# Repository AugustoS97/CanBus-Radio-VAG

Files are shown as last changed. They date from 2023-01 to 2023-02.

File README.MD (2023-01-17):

# CAN BUS interface for powering up the DSP/Sound System Amplifier for SKODA, VOLKSWAGEN, AUDI AND SEAT vehicules with non original radios

System for switching on original speakers amplifier and DSP with CAN BUS control.

Tested in a Skoda Octavia 1Z (year 2005) Edition 100 with Audience radio (6-CD changer included) and 12-speaker Sound system with active DSP controlled by CAN BUS (model 1Z0 035 456).

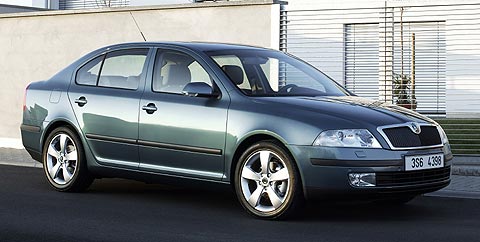
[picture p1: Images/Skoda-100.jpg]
Octavia Skoda Octavia Edition 100 (Model tested)


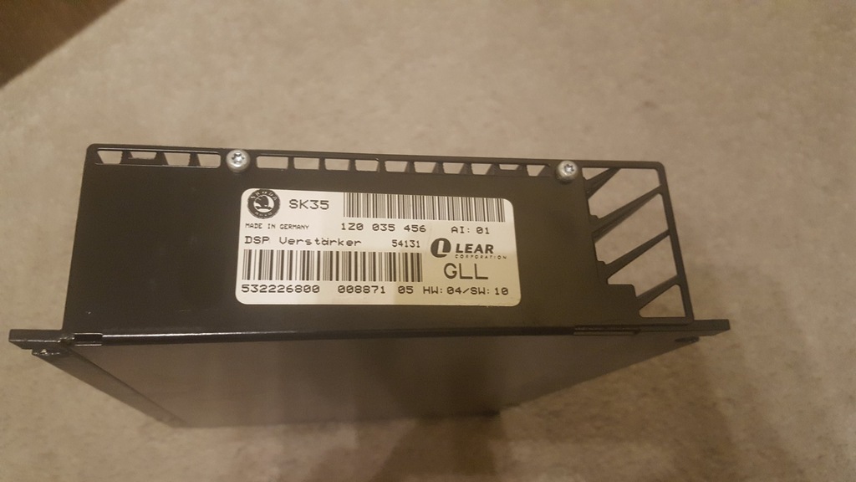
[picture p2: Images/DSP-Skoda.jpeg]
DSP Skoda DSP Picture


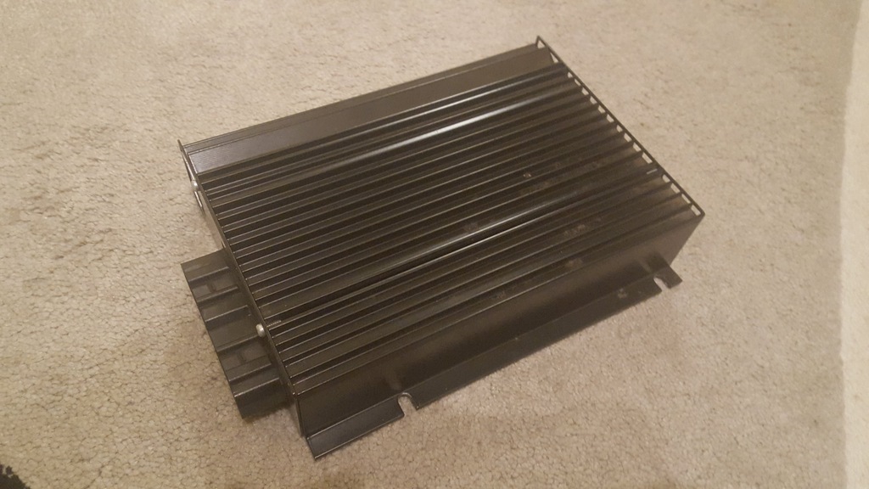
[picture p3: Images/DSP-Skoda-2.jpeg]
DSP Skoda TOP DSP TOP Picture


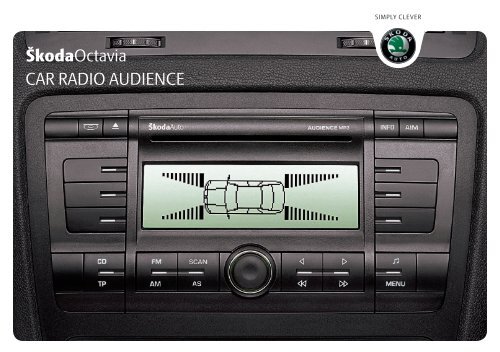
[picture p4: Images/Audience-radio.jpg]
Original radio Audience Original Car Radio


## Solution provided

A CAN controller has been developed using an ATMega 328P microcontroller (Arduino) and the CAN BUS MCP2515 interface with a TJA1050T transceiver. It allows direct power supply to the vehicle voltage (up to 20V) thanks to the MP2307 DC/DC regulator.

This interface enables the following functions:
- Switching on the sound/amplifier controller, active equaliser or DSP of a VAG group vehicle.
- Getting a 12V signal when the vehicle's ignition is switched on (work in progress).
- Getting a 12V signal when the reverse gear is engaged (work in progress).
- Control a fan to cool the vehicle radio when the vehicle radio is on.
- Getting a signal from the steering wheel controls to integrate them into a conventional radio (work in progress).

### Prototipe

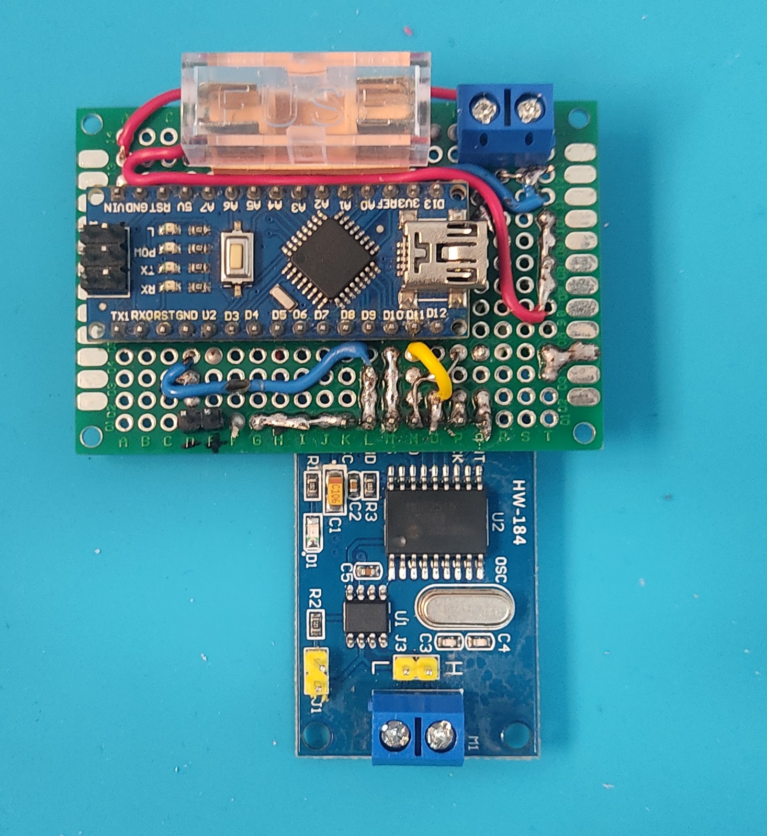
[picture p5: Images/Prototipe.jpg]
Prototipe


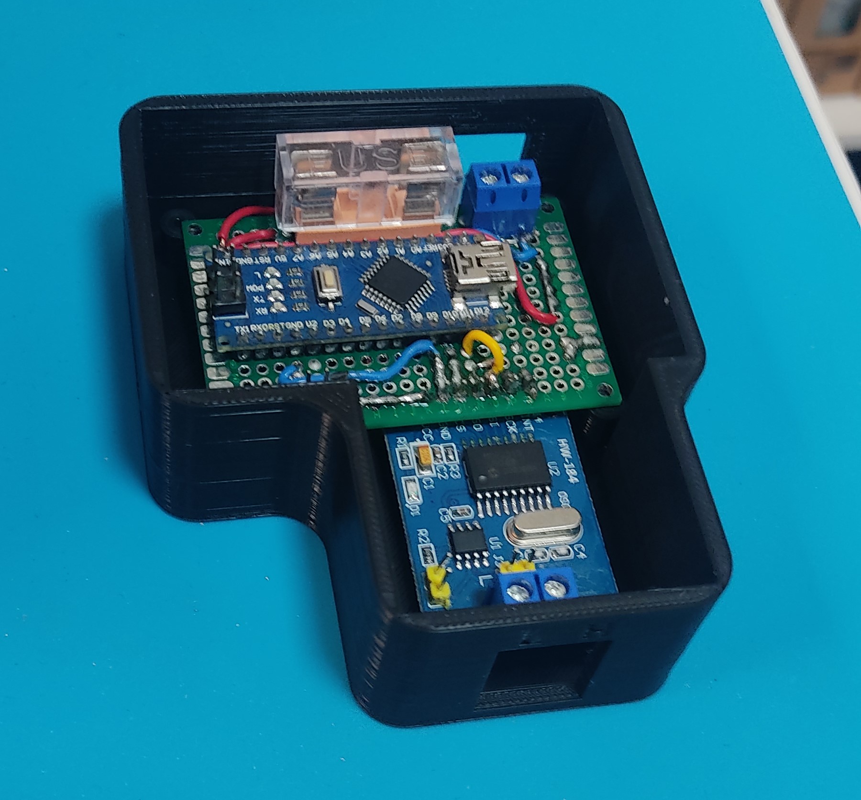
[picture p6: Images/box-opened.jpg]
Box top


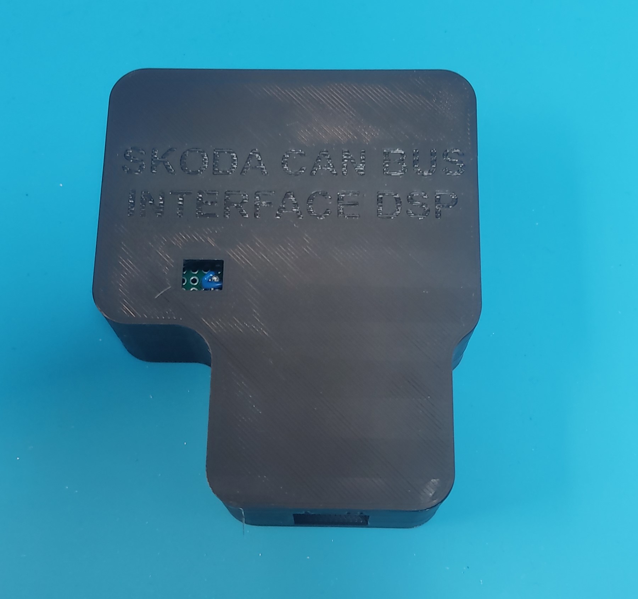
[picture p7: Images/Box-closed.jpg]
Box closed


### Final solution

The PCB designed has a JST XH 2.54 connector with 8 pins to connect to the radio and car wires. Also the interface has a ICSP and Serial connection to program and debug.

#### Electronic eschema

The connection eschema and PCB design is the following:

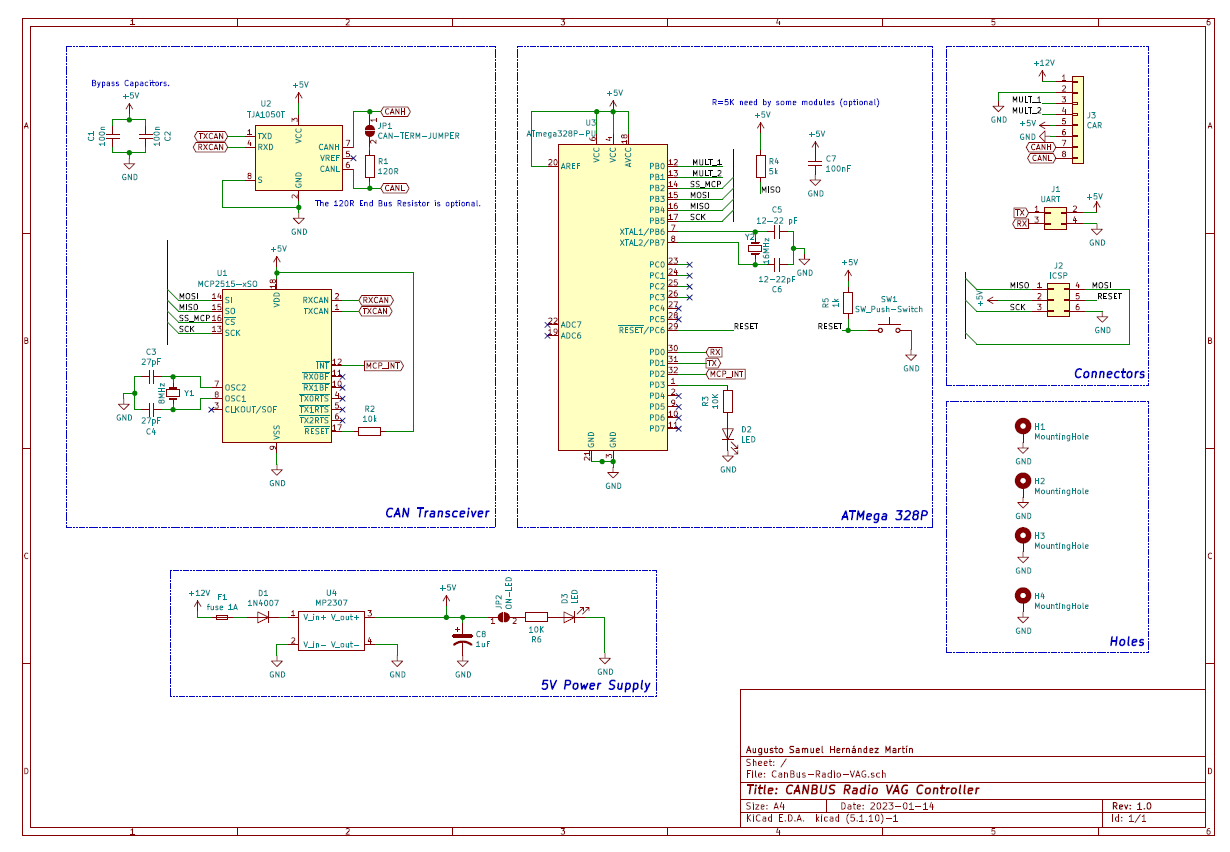
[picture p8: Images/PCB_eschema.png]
Eschema


#### PCB Designed

The 3D model of the PCB is as follow:

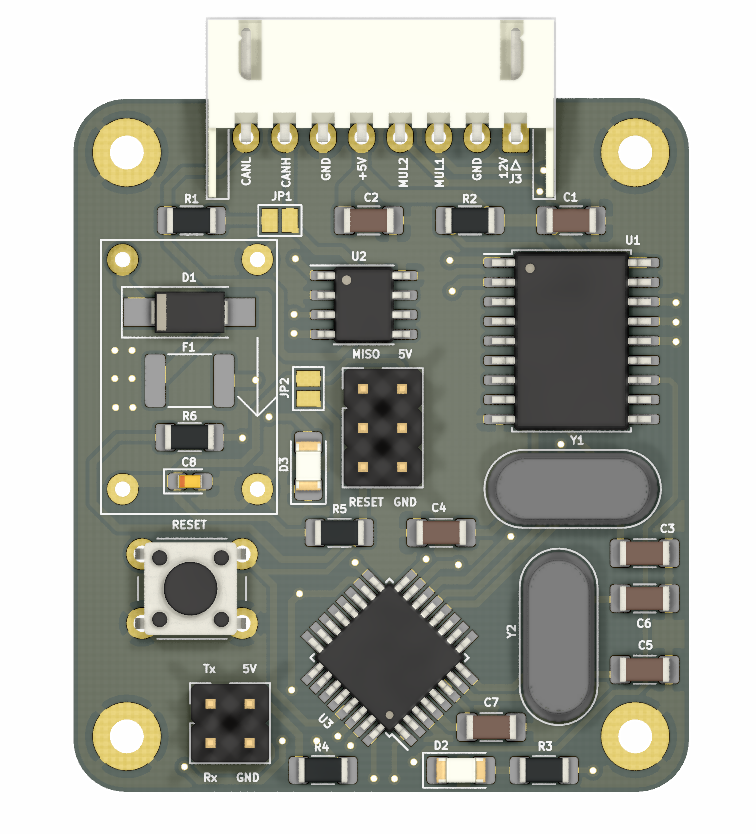
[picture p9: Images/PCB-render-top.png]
PCB TOP


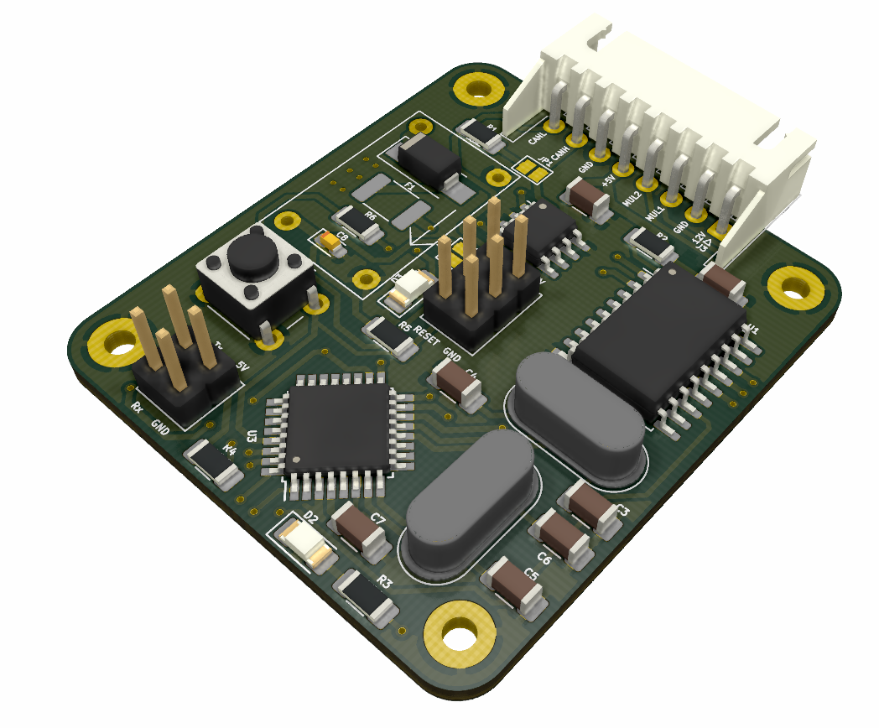
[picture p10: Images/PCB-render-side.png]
PCB SIDE


### Working in vehicule

It has been tested in my Skoda Octavia with an Android chineese radio, and using the module developed it is possible to use the original amplifier with the original soundsystem. Without this CAN Controller it is not possible to power on the DSP, so is impossible to get sound by the speakers. 

Here is possible to see some pictures of the process:

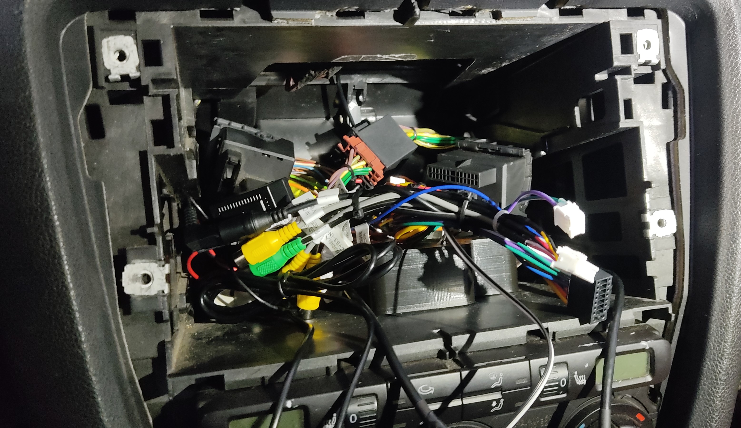
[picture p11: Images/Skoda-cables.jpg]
Making some wires


- Work in progress.

## In-vehicle wiring diagram with any radio

The connection to the module must be made as follows:

- 12V in, must be connected to an ignition after contact or to the AMP REMOTE pin of the radio, so that the module is only activated when the radio is switched on.
- GND, must be connected to the vehicle chassis or to a GND of the radio.
- CAN H, must be connected to the CAN HIGH pin of the vehicle (on the FAKRA connector)
- CAN L, must be connected to the vehicle's CAN LOW pin (on the FAKRA connector)
- Mult1 and Mult 2, are reverse and ignition signals (development in progress).

## Software requirements

To load the code on the developed board, an ISP programmer and the Arduino IDE must be used.
- The libraries required for the project are as follows:
  - [CAN Shield library](https://github.com/coryjfowler/MCP_CAN_lib)

## BOM for PCB

It is possible to find the BOM with the LCSC reference [here](/Electronic/PCB/CanBus-Radio-VAG-V1.0/ASSEMBLY/CanBus-Radio-VAG-V1.0-BOM.xlsx).

Also, the GERBER file for one PCB and for a panel (panelizing the order, you can reduce the cost) is available [here](/Electronic/PCB/CanBus-Radio-VAG-V1.0/GERBER/CanBus-Radio-VAG-V1-Gerber.zip).

## Extra functions

To activate the front sensors from the vehicle's parking button, the power pin of the parking button connector must be connected to the reverse signal from the camera. It is recommended that a 1N4007 diode is used to prevent current flowing back to the button from the radio or from the button to the CAN BUS module.

Here you can see an scheme of this connection.

## Buy the CAN Controller

If you want to buy a CAN Controller to enable your DSP and use the original sound system with non-stock radios in Volkswagen, Audi, Skoda and Seat, you can contact with me by email (augustosamuelhdezmartin@gmail.com) or you can buy it in E-bay here.

## Other tools

Also there is a [folder](/Arduino/tools/CanHacker/) with the CAN HACKER software and the code to upload to Arduino to use a MCP2515 module + Arduino Nano as a CAN BUS sniffer and get all the message in the PC using the CAN HACKER software. With this method I could find the radio messages, so I could create this CAN BUS interface.

## Links of interest

Some interesting links:

- [A way to use stock amp with after market radio SKODA](https://www.briskoda.net/forums/topic/449813-solved-better-way-of-using-stock-amp-with-after-market-radio/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)
- [How to use after market radio with the stock amplifier in SKODA, SEAT, VOLKSWAGEN and AUDI cars](https://www.briskoda.net/forums/topic/378504-solved-how-to-use-stock-amplifier-with-after-market-hu/)

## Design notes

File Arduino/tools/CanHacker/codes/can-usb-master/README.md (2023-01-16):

# CanHacker (lawicel) CAN adapter on Arduino + MCP2515

Testes with Arduino Nano.
On Arduino Uno have problem with too long boot period and losing first command when work with CanHacker application

## Installation

1. Install [MCP2515 Library](https://github.com/autowp/arduino-mcp2515)
2. Install [CanHacker Library](https://github.com/autowp/arduino-canhacker)
3. Configure sketch: MCP2515 CS pin, SoftwareSerial pins if required, change baudrates
4. Use with [CanHacker](http://www.mictronics.de/projects/usb-can-bus/) or CANreader (soon)

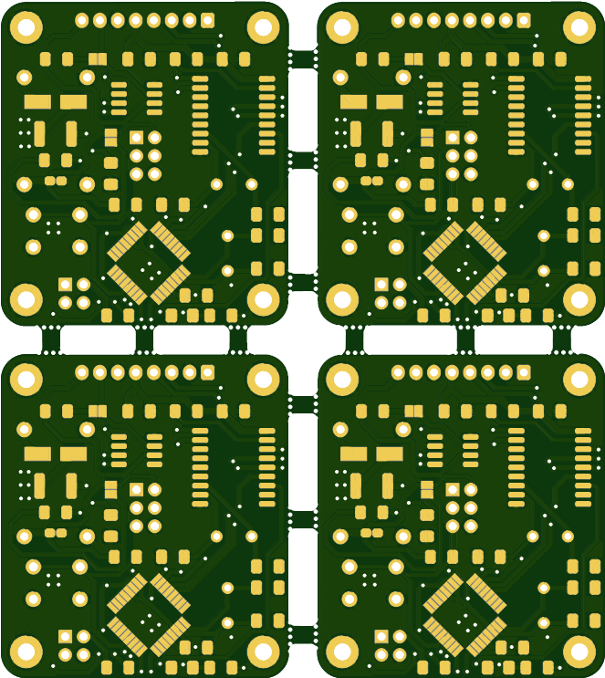
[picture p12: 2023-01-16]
Electronic/PCB/CanBus-Radio-VAG-V1.0/GERBER/Panelize/Untitled_Combined_Top.png

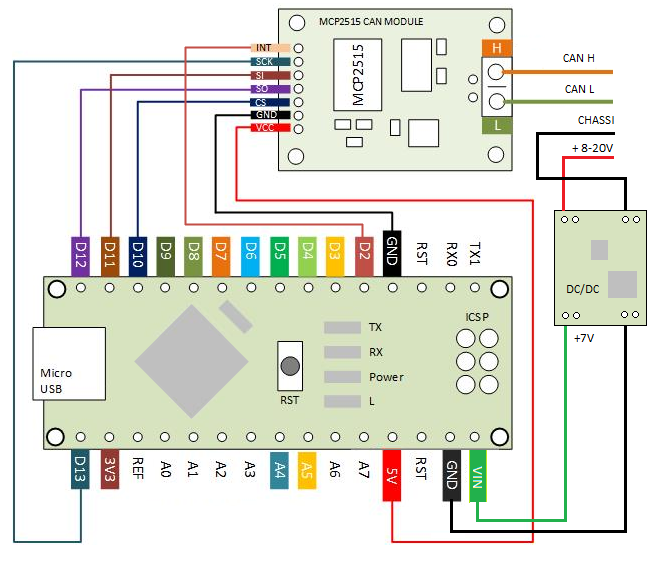
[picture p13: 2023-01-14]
Electronic/Eschemes/Esquema.png

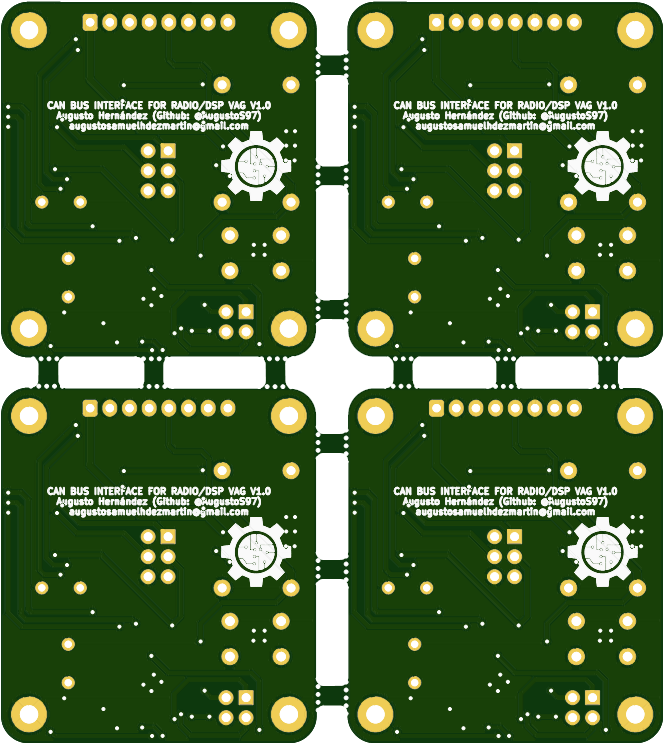
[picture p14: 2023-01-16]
Electronic/PCB/CanBus-Radio-VAG-V1.0/GERBER/Panelize/Untitled_Combined_Bottom.png

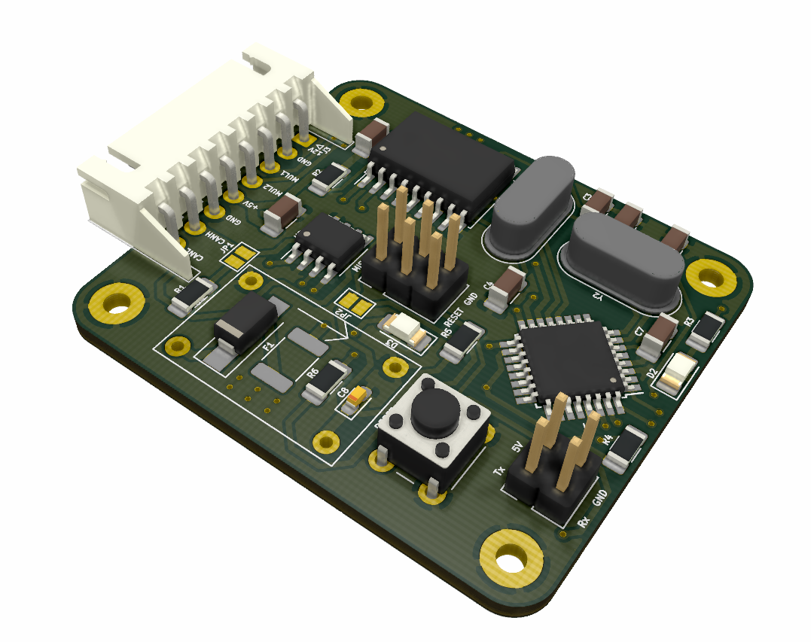
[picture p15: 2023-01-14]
Images/PCB-render-other-side.png

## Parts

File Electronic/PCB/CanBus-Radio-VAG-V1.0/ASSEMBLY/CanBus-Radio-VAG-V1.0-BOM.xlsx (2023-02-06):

 | Columna2 | Columna3 | Columna1 | Columna4
Comment | Designator | Footprint | LCSC Part Number | Qnty
100n | C1, C2, C7 | Capacitor_SMD:C_1206_3216Metric_Pad1.33x1.80mm_HandSolder | C840121 | 3
27pF | C3, C4, | Capacitor_SMD:C_1206_3216Metric_Pad1.33x1.80mm_HandSolder | C1899 | 2
22pF | C5, C6 | Capacitor_SMD:C_1206_3216Metric_Pad1.33x1.80mm_HandSolder | C565687 | 2
1uF | C8, | Capacitor_Tantalum_SMD:CP_EIA-1608-10_AVX-L_Pad1.25x1.05mm_HandSolder | C307912 | 1
1N4007 | D1, | Diode_SMD:D_SMA_Handsoldering | C2909831 | 1
LED | D2, D3, | LED_SMD:LED_1206_3216Metric_Pad1.42x1.75mm_HandSolder | C375458 | 2
fuse 1A | F1, | Fuse:Fuse_1812_4532Metric_Pad1.30x3.40mm_HandSolder | C151169 | 1
UART | J1, | Connector_PinHeader_2.54mm:PinHeader_2x02_P2.54mm_Vertical | C706892 | 1
ICSP | J2, | Connector_PinHeader_2.54mm:PinHeader_2x03_P2.54mm_Vertical | C706893 | 1
CAR | J3, | Connector_JST:JST_XH_S8B-XH-A-1_1x08_P2.50mm_Horizontal |  | 1
120R | R1, | Resistor_SMD:R_1206_3216Metric_Pad1.30x1.75mm_HandSolder | C114928 | 1
10k | R2, | Resistor_SMD:R_1206_3216Metric_Pad1.30x1.75mm_HandSolder | C3018037 | 1
10K | R3, R6, | Resistor_SMD:R_1206_3216Metric_Pad1.30x1.75mm_HandSolder | C3018037 | 2
5k | R4, | Resistor_SMD:R_1206_3216Metric_Pad1.30x1.75mm_HandSolder | C136458 | 1
1k | R5, | Resistor_SMD:R_1206_3216Metric_Pad1.30x1.75mm_HandSolder | C408770 | 1
SW_Push-Switch | SW1, | Button_Switch_THT:SW_PUSH_6mm_H5mm | C2828578 | 1
MCP2515-xSO | U1, | Package_SO:SOIC-18W_7.5x11.6mm_P1.27mm | C12368 | 1
TJA1050T | U2, | Package_SO:SOIC-8_3.9x4.9mm_P1.27mm | C6952 | 1
ATmega328P-PU | U3, | SmartBMS:TQFP-32_7x7mm_P0.8mm | C14877 | 1
8MHz | Y1, | Crystal:Crystal_HC49-4H_Vertical | C655216 | 1
16MHz | Y2, | Crystal:Crystal_HC49-4H_Vertical | C390745 | 1

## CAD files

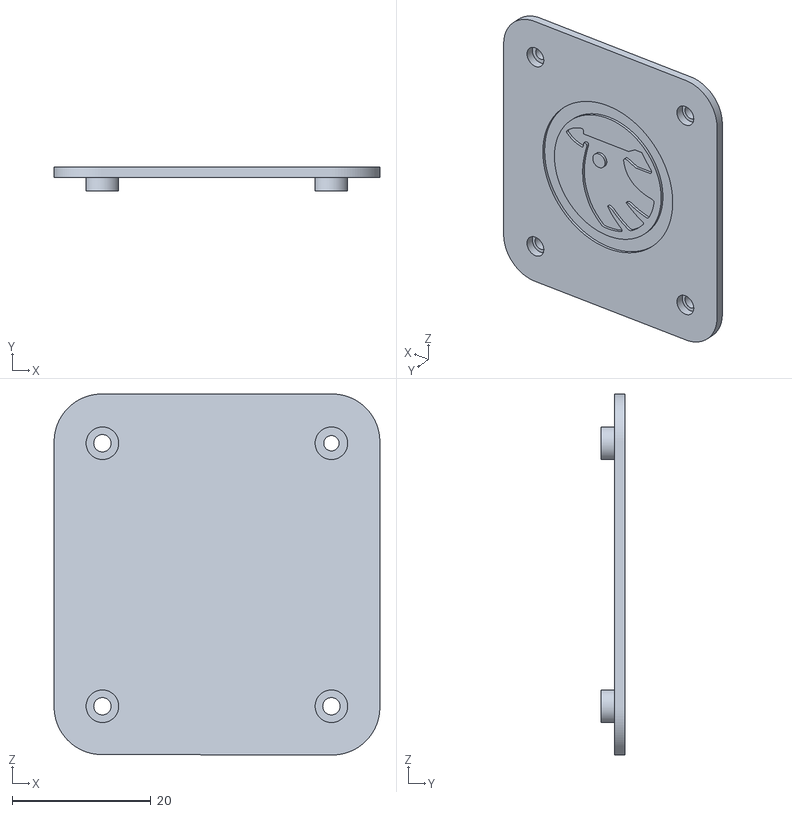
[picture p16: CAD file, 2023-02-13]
3D Design/Case V1.0/STL/Tapa.stl
46.9 x 3.50 x 52.0

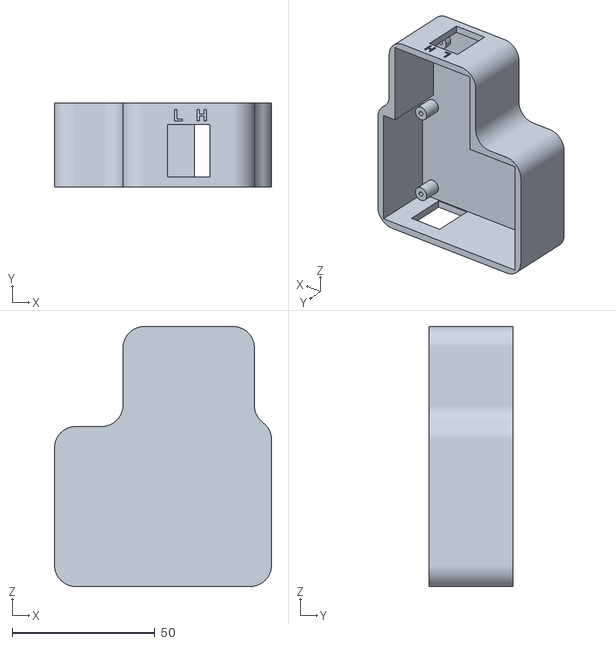
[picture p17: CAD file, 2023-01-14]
3D Design/Prototyping/STL/Base.stl
76.0 x 29.5 x 91.0

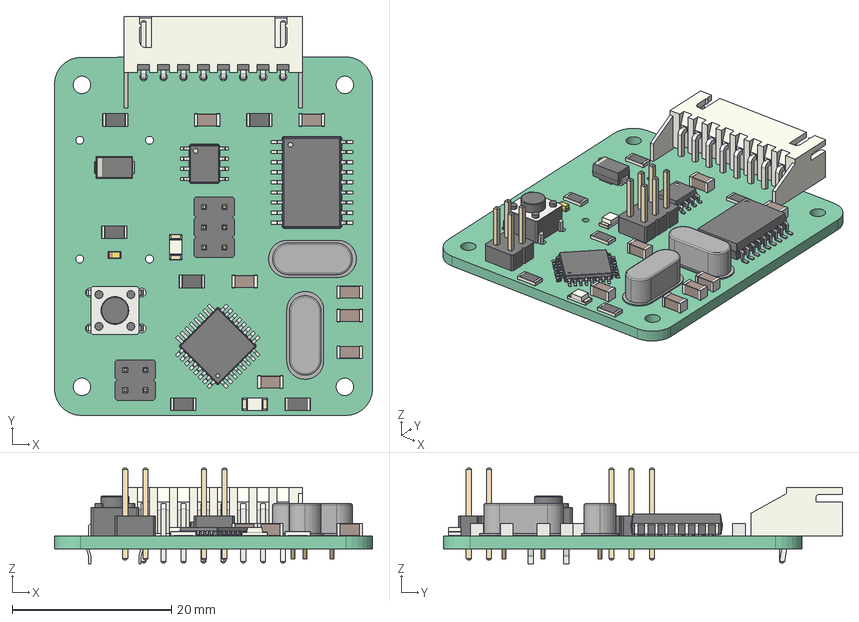
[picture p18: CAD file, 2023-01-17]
Electronic/PCB/CanBus-Radio-VAG-V1.0/3D Models/CanBus-Radio-VAG-CanBus-Radio-VAG.step
39.9 x 50.1 x 12.0 mm
Pcb_fef1
C1_C_1206_3216Metric_000063c35973 x 7
C8_CP_EIA_1608_10_AVX_L_000063c359ec
D1_D_SMA_000063c35a0b
D2_LED_1206_3216Metric_000063c35a1e x 2
J1_PinHeader_2x02_P254mm_Vertical_000063c35a7c
J2_PinHeader_2x03_P254mm_Vertical_000063c35a98
J3_JST_S8B_XH_A_1_000063c35ae0
R1_R_1206_3216Metric_000063c35b0d x 6
SW1_SW_PUSH_6mm_h5mm_000063c35b81
U1_SOIC_18W_75x116mm_P127mm_000063c35baa
U2_SOIC_8_39x49mm_P127mm_000063c35bc4
Y1_Crystal_HC49-4H_Vertical_000063c35bdb x 2
U3_TQFP_32_7x7mm_P08mm_000063c36874

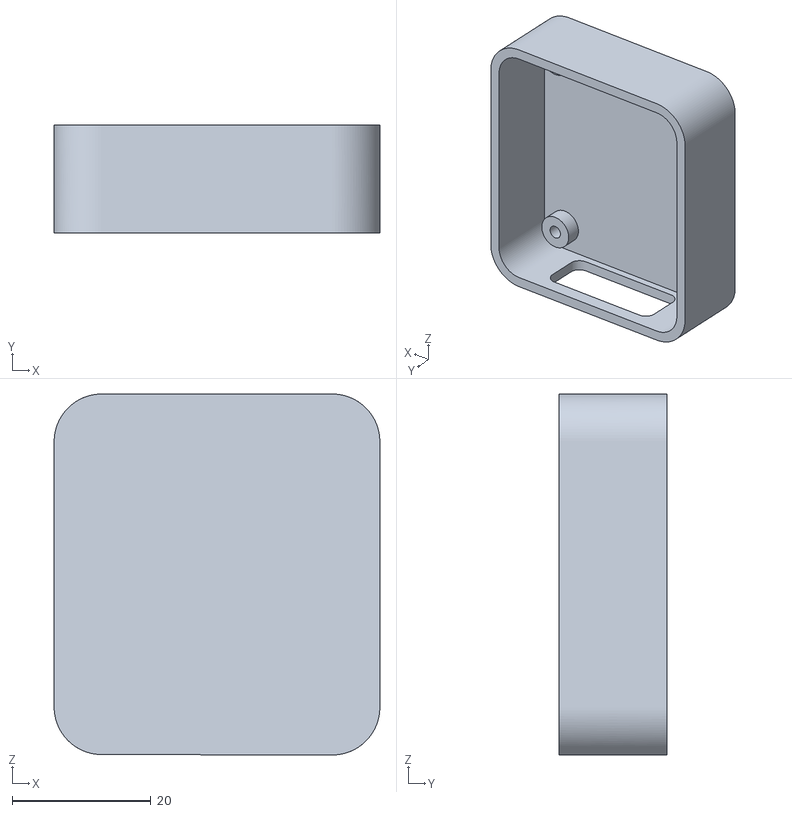
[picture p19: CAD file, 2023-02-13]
3D Design/Case V1.0/STL/Caja.stl
46.9 x 15.5 x 52.0

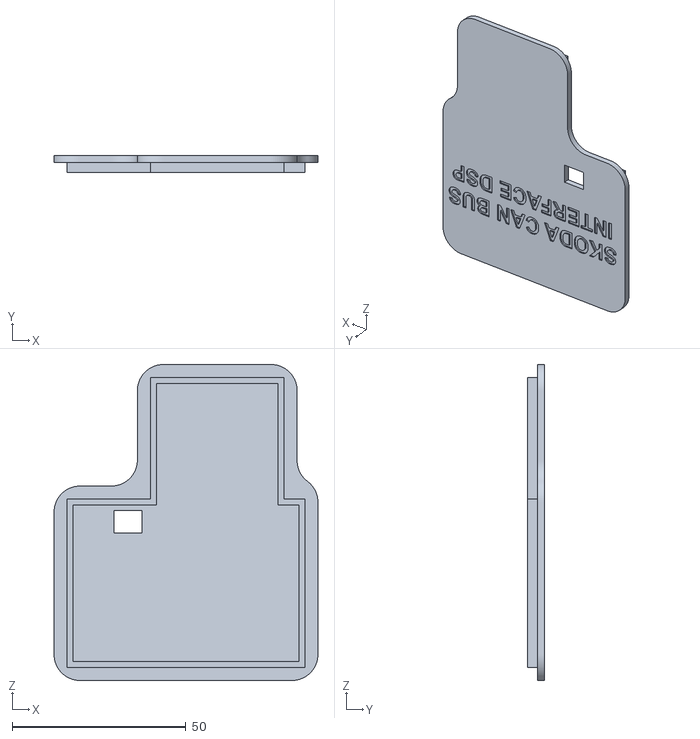
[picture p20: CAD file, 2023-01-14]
3D Design/Prototyping/STL/Tapa.stl
76.0 x 5.00 x 91.0

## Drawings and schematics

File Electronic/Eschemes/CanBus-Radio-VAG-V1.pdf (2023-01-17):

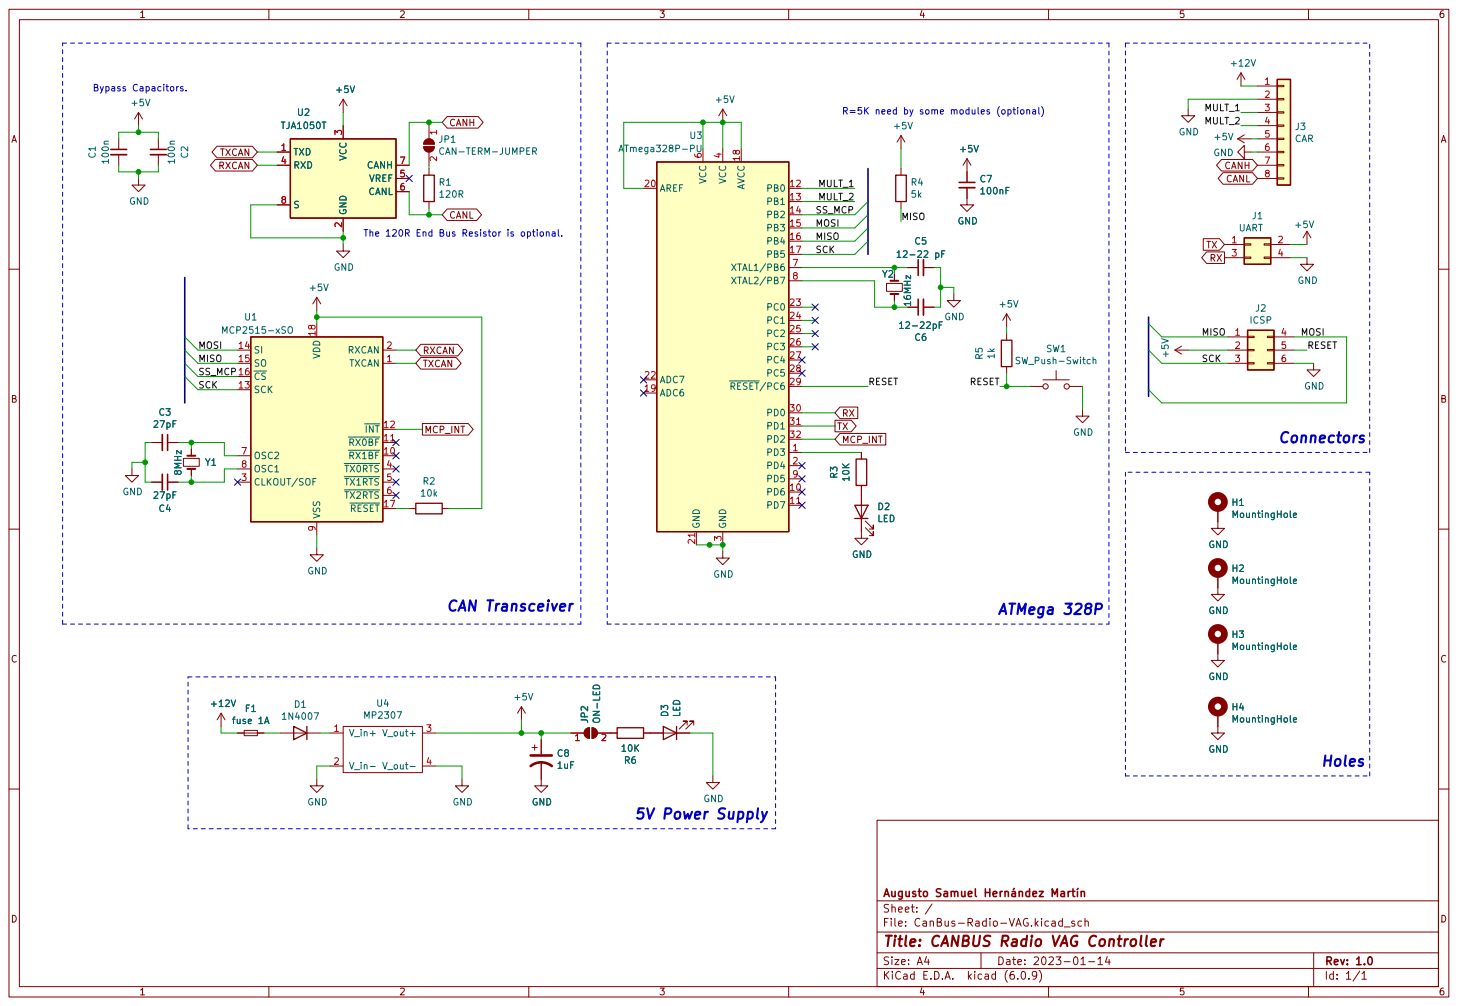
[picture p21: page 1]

R=5K need by some modules (optional)

3 RXD 4 VREF 5 CANL 6 CANH 7 S

1 2 JP1 CAN-TERM-JUMPER GND +5V

The 120R End Bus Resistor is optional.

5V Power Supply JP2 ON-LED

File: CanBus-Radio-VAG.kicad_sch Sheet: / þÿAugusto Samuel Hernández Martín

Id: 1/1 Title: CANBUS Radio VAG Controller

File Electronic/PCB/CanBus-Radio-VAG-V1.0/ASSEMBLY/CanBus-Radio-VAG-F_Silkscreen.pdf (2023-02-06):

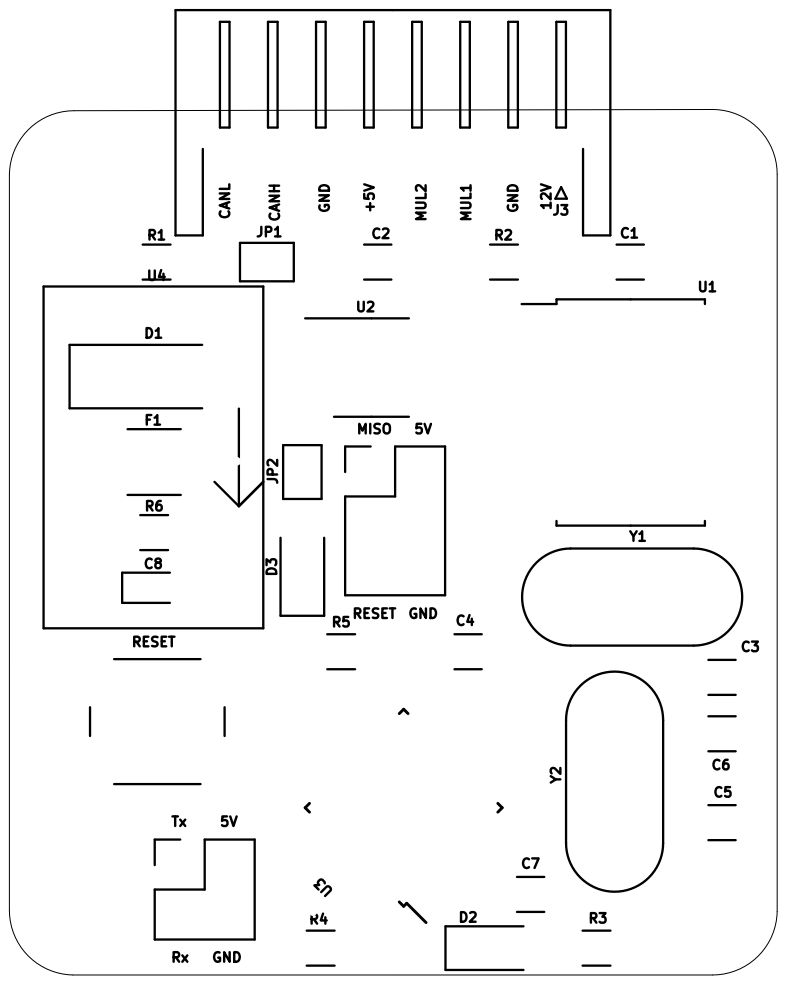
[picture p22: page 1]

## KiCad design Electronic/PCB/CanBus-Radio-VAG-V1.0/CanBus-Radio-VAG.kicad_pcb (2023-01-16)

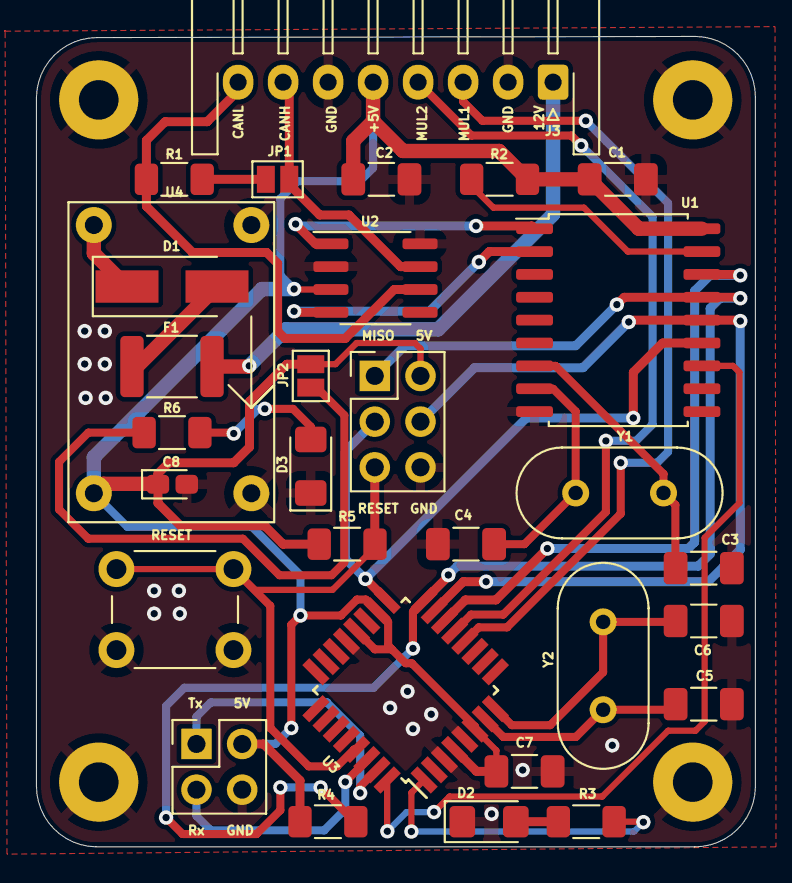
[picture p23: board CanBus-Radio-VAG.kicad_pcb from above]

Board: 2 copper layers, 39.9 x 45.0 mm, 34 parts (0 on the bottom side), 29 nets.

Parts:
C1, C2: 100n; C_1206_3216Metric_Pad1.33x1.80mm_HandSolder
C3, C4: 27pF; C_1206_3216Metric_Pad1.33x1.80mm_HandSolder
C5: 12-22 pF; C_1206_3216Metric_Pad1.33x1.80mm_HandSolder
C6: 12-22pF; C_1206_3216Metric_Pad1.33x1.80mm_HandSolder
C7: 100nF; C_1206_3216Metric_Pad1.33x1.80mm_HandSolder
C8: 1uF; CP_EIA-1608-10_AVX-L_Pad1.25x1.05mm_HandSolder
D1: 1N4007; D_SMA_Handsoldering
D2, D3: LED; LED_1206_3216Metric_Pad1.42x1.75mm_HandSolder
F1: fuse 1A; Fuse_1812_4532Metric_Pad1.30x3.40mm_HandSolder
H1, H2, H3, H4: MountingHole; MountingHole_2.2mm_M2_Pad
J1: UART; PinHeader_2x02_P2.54mm_Vertical
J2: ICSP; PinHeader_2x03_P2.54mm_Vertical
J3: CAR; JST_XH_S8B-XH-A-1_1x08_P2.50mm_Horizontal
JP1: CAN-TERM-JUMPER; SolderJumper-2_P1.3mm_Open_Pad1.0x1.5mm
JP2: ON-LED; SolderJumper-2_P1.3mm_Open_Pad1.0x1.5mm
R1: 120R; R_1206_3216Metric_Pad1.30x1.75mm_HandSolder
R2: 10k; R_1206_3216Metric_Pad1.30x1.75mm_HandSolder
R3, R6: 10K; R_1206_3216Metric_Pad1.30x1.75mm_HandSolder
R4: 5k; R_1206_3216Metric_Pad1.30x1.75mm_HandSolder
R5: 1k; R_1206_3216Metric_Pad1.30x1.75mm_HandSolder
SW1: SW_Push-Switch; SW_PUSH_6mm_H5mm
U1: MCP2515-xSO; SOIC-18W_7.5x11.6mm_P1.27mm
U2: TJA1050T; SOIC-8_3.9x4.9mm_P1.27mm
U3: ATmega328P-PU; TQFP-32_7x7mm_P0.8mm
U4: MP2307
Y1: 8MHz; Crystal_HC49-4H_Vertical
Y2: 16MHz; Crystal_HC49-4H_Vertical

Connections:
+5V: C1.1, C2.1, C7.1, C8.1, J1.2, J2.2, J3.5, JP2.1, R2.1, R4.1, R5.1, U1.18, U2.3, U3.4, U3.6, U3.18, U3.20, U4.3
+12V: F1.1, J3.1
/MISO: J2.1, R4.2, U1.15, U3.16
/MOSI: J2.4, U1.14, U3.15
/MULT_1: J3.3, U3.12
/MULT_2: J3.4, U3.13
/RESET: J2.5, R5.2, SW1.1, U3.29
/SCK: J2.3, U1.13, U3.17
/SS_MCP: U1.16, U3.14
CANH: J3.7, JP1.1, U2.7
CANL: J3.8, R1.2, U2.6
GND: C1.2, C2.2, C3.2, C4.2, C5.2, C6.2, C7.2, C8.2, D2.1, D3.1, H1.1, H2.1, H3.1, H4.1, J1.4, J2.6, J3.2, J3.6, SW1.2, U1.9, U2.2, U2.8, U3.3, U3.5, U3.21, U4.2, U4.4
MCP_INT: U1.12, U3.32
unnamed: C3.1, U1.7, Y1.1
unnamed: C4.1, U1.8, Y1.2
unnamed: C5.1, U3.7, Y2.2
unnamed: C6.1, U3.8, Y2.1
unnamed: D1.1, U4.1
unnamed: D1.2, F1.2
unnamed: D2.2, R3.2
unnamed: D3.2, R6.2
unnamed: JP1.2, R1.1
unnamed: JP2.2, R6.1
unnamed: R2.2, U1.17
unnamed: R3.1, U3.1
RX: J1.3, U3.30
RXCAN: U1.2, U2.4
TX: J1.1, U3.31
TXCAN: U1.1, U2.1

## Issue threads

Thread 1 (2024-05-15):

Trying to simulate ignition

veso266, 2024-05-15:
Hello there
I have a test bench for PQ platform which you can see on the picture: https://imgur.com/fyGPqXu

On my Bench is RNS510 and 3C0 907 530 L gateway module

I would like to simulate ignition message
I use MCP2515 module with my Arduino (seerduino the only difference is that u can also put it on 3.3V operation instead of 5V)

I also discovered that VW (I believe all VAG vehicles are the same) PQ cars have 3 canbuses: https://imgur.com/a/FAXZZzY
Infotaiment - 100kbps
Conveniences - 100kbps
Drive train - 500kbps

I was able to throw together this little test program to trying to simulate ignition message
I tried to use this library: https://github.com/autowp/arduino-mcp2515/tree/master
```c
#include <SPI.h>
#include "mcp25151.h"

//MCP_CAN CAN0(10);     // Set CS to pin 10
MCP2515 mcp2515(10); // Set CS to pin 10

struct can_frame canMsg;

void sendCAN(uint32_t id, uint8_t length, uint8_t data0 = 0x00 , uint8_t data1 = 0x00 , uint8_t data2 = 0x00 , uint8_t data3 = 0x00 , uint8_t data4 = 0x00 , uint8_t data5 = 0x00 , uint8_t data6 = 0x00 , uint8_t data7 = 0x00);

void setup() {
  Serial.begin(115200);

  // Initialize MCP2515 running at 8MHz with a baudrate of 100kb/s and the masks and filters disabled.
  //if(CAN0.begin(MCP_ANY, CAN_500KBPS, MCP_8MHZ) == CAN_OK) Serial.println("MCP2515 Initialized Successfully!");
  //else Serial.println("Error Initializing MCP2515...");

  //CAN0.setMode(MCP_NORMAL);   // Change to normal mode to allow messages to be transmitted

  Serial.println("SetBitrate: " + String(mcp2515.setBitrate(CAN_500KBPS, MCP_8MHZ)));
  Serial.println("SetMode: " + String(mcp2515.setNormalMode()));
  Serial.println("VW CAN Interface");

}

void loop() {
  sendCAN(0x271, 2, 0x01, 0x80); //Ignition on

  //3 bytes 1. byte hat 0 wenn licht aus und 0x5C wenn licht an
  sendCAN(0x635, 3, 0x00, 0xFF, 0x00); //Light on

//7 bytes 1st byte bit 1 reverse gear
  //sendCAN(0x351, 7, 0x00, 0x01, 0x00, 0x02, 0x00, 0x00, 0x7E, 0x7E); //Car is in reverse

  delay(100);

}

void sendCAN(uint32_t id, uint8_t length, uint8_t data0 , uint8_t data1 , uint8_t data2 , uint8_t data3 , uint8_t data4 , uint8_t data5 , uint8_t data6 , uint8_t data7) {
  struct can_frame canMsg1;
  canMsg1.can_id  = id;
  canMsg1.can_dlc = length;
  canMsg1.data[0] = data0;
  canMsg1.data[1] = data1;
  canMsg1.data[2] = data2;
  canMsg1.data[3] = data3;
  canMsg1.data[4] = data4;
  canMsg1.data[5] = data5;
  canMsg1.data[6] = data6;
  canMsg1.data[7] = data7;
  mcp2515.sendMessage(MCP2515::TXB1, &canMsg1);
}
```

The problem is that nothing happens
If I disconnect the gateway, connect to 100kbps inforaiment bus according to this gateway pinout

```
1,2 - +12v (connection 30)
14 - +12v (connection 15 [Ignition])
11,12 - Ground connection
6 - powertrain CAN bus, low
16 - powertrain CAN bus, high
9 - DIAGNOSE can low
19 - DIAGNOSE can high
8 - Dashboard can low
18 - Dashboard can high
5 - convenience CAN bus, low
15 - convenience CAN bus, high
10 - infotainment CAN bus, low
20 - infotainment CAN bus, high
13 - to Dashboard pin15
```

my radio (RNS510 is not happy: https://imgur.com/B4BlY3l)
if gateway is connected, this is what RNS510 displays: https://imgur.com/PAH2PBI

The problem is that I have no acsess to any PQ vehicle anymore so I don't have any real data so maybe am I not generating a proper message or my wiring is not correct, I don't know

So I would like to try to come to a common denominator, like SW is OK, my Hardware is faulty, so I was wondering if you maybe have some example code that would simulate ignition or turn lights on your radio on and you know that it does work so I could be sure, ok, this code should generate a proper walkup message and my hardware/connnections is not OK

BTW: if I connect to a drive train (500kbps bus), I can clearly see proper messages
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

so maybe I just am not generating a proper walkup signal or my timings are not correct, idk

Thanks for Anwsering and Best Regards

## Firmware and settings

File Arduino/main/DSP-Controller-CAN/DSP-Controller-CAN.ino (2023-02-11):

/* Arduino code to send CAN message to enable some car functions in Volkswagen, Skoda, SEAT and Audi (VW AG).
 * This version allows to enable the original sound amplifier with a non-original radio.
 * Tested in a Skoda Octavia 1Z (2005) Edition 100 with Sound System (12 speakers)
 * Author: Augusto Samuel Hernandez Martin (Github: @AugustoS97)
 * Date: 10/01/2023
 */

//Libraries to work with can bus
#include <mcp_can.h> 
#include <SPI.h>

MCP_CAN CAN0(10);     // Set CS to pin 10

void setup(){
  pinMode(3, OUTPUT); //Config the output for the status LED
  digitalWrite(3, HIGH); //Power on the LED
  Serial.begin(115200); //Serial COM to debug

  // Initialize MCP2515 running at 8MHz with a baudrate of 100kb/s and the masks and filters disabled.
  // Infotainment CAN BUS uses 100kb/s in Skoda.

  if(CAN0.begin(MCP_ANY, CAN_100KBPS, MCP_8MHZ) == CAN_OK){
    Serial.println("MCP2515 Initialized Successfully!");
    digitalWrite(3, LOW); //Power off the RED LED
  }

  else{ //If there is an error initializing  interface, wait for a reset here.
    Serial.println("Error Initializing MCP2515...");
    while(true){
      digitalWrite(3, HIGH);
      delay(100);
      digitalWrite(3, LOW);
      delay(100);
    }
  }

  CAN0.setMode(MCP_NORMAL);   // Change to normal mode to allow messages to be transmitted

}

void loop(){

  // Send data to enable Spekaer Amplifiers: 
  // ID = 0x507, Standard CAN Frame, Data length = 6 bytes, 'data' = array of data bytes to send
  // Data: 0x03, 0x00, 0x00, 0x00, 0x00, 0x00

  unsigned char stmp0[6] = {0x03, 0x00, 0x00, 0x00, 0x00, 0x00};
  digitalWrite(3, HIGH); //Power on the LED
  byte sndStat0 = CAN0.sendMsgBuf(0x507, 0, 6, stmp0);
  delay(100); //Wait 100 ms to power-off
  digitalWrite(3, LOW); //Power off the LED
  delay(4900);   // send data every 5000ms
  
}

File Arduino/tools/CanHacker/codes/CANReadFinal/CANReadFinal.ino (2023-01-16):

// demo: CAN-BUS Shield, receive data with check mode
// send data coming to fast, such as less than 10ms, you can use this way
// loovee, 2014-6-13
#include <SPI.h>

#define CAN_2515
// #define CAN_2518FD

// Set SPI CS Pin according to your hardware

#if defined(SEEED_WIO_TERMINAL) && defined(CAN_2518FD)
// For Wio Terminal w/ MCP2518FD RPi Hat：
// Channel 0 SPI_CS Pin: BCM 8
// Channel 1 SPI_CS Pin: BCM 7
// Interupt Pin: BCM25
const int SPI_CS_PIN  = BCM8;
const int CAN_INT_PIN = BCM25;
#else

// For Arduino MCP2515 Hat:
// the cs pin of the version after v1.1 is default to D9
// v0.9b and v1.0 is default D10
const int SPI_CS_PIN = D8;
const int CAN_INT_PIN = D4;
#endif


#ifdef CAN_2518FD
#include "mcp2518fd_can.h"
mcp2518fd CAN(SPI_CS_PIN); // Set CS pin
#endif

#ifdef CAN_2515
#include "mcp2515_can.h"
mcp2515_can CAN(SPI_CS_PIN); // Set CS pin
#endif                           

void setup() {
    SERIAL_PORT_MONITOR.begin(115200);

    while (CAN_OK != CAN.begin(CAN_500KBPS)) {             // init can bus : baudrate = 500k
        SERIAL_PORT_MONITOR.println("CAN init fail, retry...");
        delay(100);
    }
    SERIAL_PORT_MONITOR.println("CAN init ok!");
}


void loop() {
    unsigned char len = 0;
    unsigned char buf[8];

    if (CAN_MSGAVAIL == CAN.checkReceive()) {         // check if data coming
        CAN.readMsgBuf(&len, buf);    // read data,  len: data length, buf: data buf

        unsigned long canId = CAN.getCanId();

        //SERIAL_PORT_MONITOR.println("-----------------------------");
        //SERIAL_PORT_MONITOR.print("Get data from ID: 0x");
        SERIAL_PORT_MONITOR.print(canId, HEX);
        Serial.print(" ");
        Serial.print(len, HEX); // print DLC
        Serial.print(" ");

        for (int i = 0; i < len; i++) { // print the data
            SERIAL_PORT_MONITOR.print(buf[i], HEX);
            SERIAL_PORT_MONITOR.print(" ");
        }
        SERIAL_PORT_MONITOR.println();
    }
}

/*********************************************************************************************************
    END FILE
*********************************************************************************************************/

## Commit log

2023-01-14 Added first design.
    [Base.stl, CanBus-Radio-VAG.kicad_pcb, CanBus-Radio-VAG.sch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]
2023-01-16 Added some tools and the panelize design.
    [CanBus-Radio-VAG-B_Cu.gbl, CanBus-Radio-VAG-B_Mask.gbs, CanBus-Radio-VAG-B_Paste.gbp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]
2023-01-17 Some changes in code
    [CanBus-Radio-VAG-CanBus-Radio-VAG.step, Monitoreo y balanceo de las celdas.sch]
2023-02-06 Some minor changes
    [CanBus-Radio-VAG-V1.0-BOM.xlsx]
2023-02-13 Case design add
    [Caja.stl, Tapa.stl]
